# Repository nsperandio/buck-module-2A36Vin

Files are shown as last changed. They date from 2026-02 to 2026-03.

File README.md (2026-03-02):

# Buck DC/DC Module [Imax=2A, Vinmax=36V, Vo=5V]
Simple DC/DC converter in an simple and usable form-factor for educational or hobbyist purposes - but still with decent EMI performance and efficiency.

>⚠️ **Work in Progress**  
This design is currently under development and has not yet been fully validated.

## Current Project Status

- [x] Basic schematic
- [x] PCB layout
- [ ] BOM 
- [ ] First prototype assembly
- [ ] Electrical validation
- [ ] Thermal characterization

## Overview
The design is based on the [LV14240](https://www.ti.com/product/LV14240) buck controller with integrated switch by Texas Instruments.

Layout is based on the "Application and Implementation" section of the datasheet.

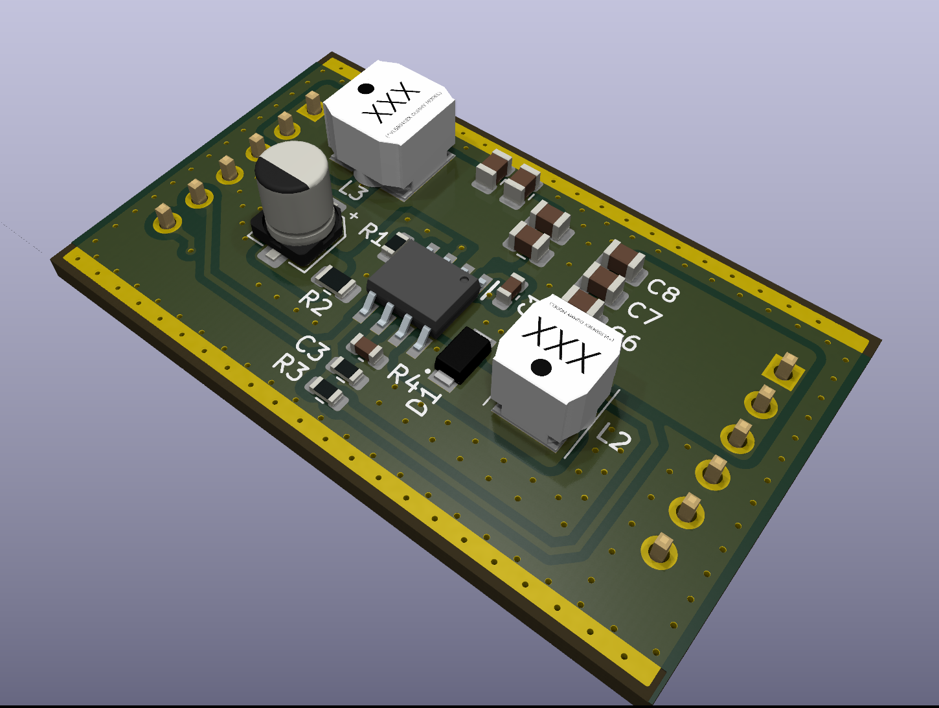
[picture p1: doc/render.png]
Buck PCB Render


## Specifications
|Spec|Value|
|-|-|
|Topology | buck (non-synchronous!)|
|Input Voltage| 4 - 36 V|
|Output Voltage| 5 V |
|Maximum Output Current| 2 A |
| Switching frequency| 500 kHz|

## EMI Considerations

An LCR input filter is added to attenuate conducted emissions at the switching frequency. The filter's damping factor can be obtained thanks to the ESR of the bulk capacitor and the DCR of the inductor. If the parasitics are not high enough an additional resistor can be used. 
The following plots refer to the components in the table. Modulus of the buck input impedance in green, modulus of the filter impedance in red:



|Spec|Value|
|-|-|
|Input Inductance| 47 uH|
|Inductors DCR| 230 mOhm|
|Bulk Capacitor| 20 uF |
|Capacitor ESR| 40 mOhm|
|Resonant peak frequency| 4.5 kHz|

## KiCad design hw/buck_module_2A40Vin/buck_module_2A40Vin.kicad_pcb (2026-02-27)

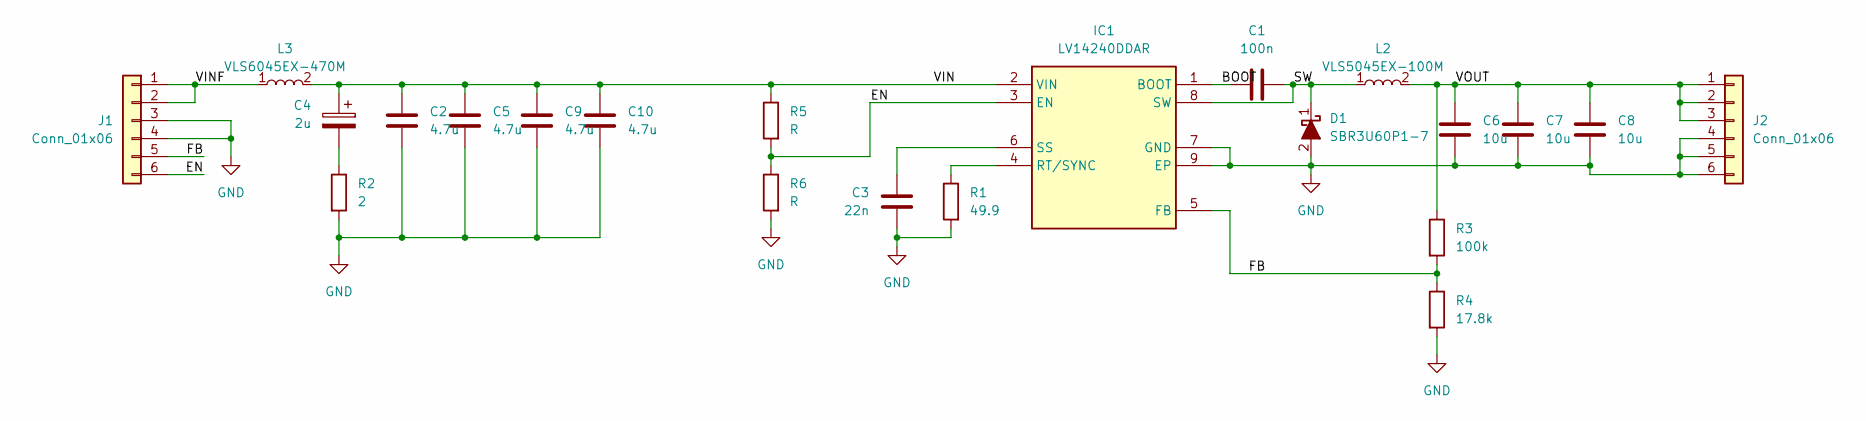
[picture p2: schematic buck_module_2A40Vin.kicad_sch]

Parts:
C1: 100n; C_0603_1608Metric; Voltage 16
C2, C5, C9, C10: 4.7u; C_0805_2012Metric; Voltage 100
C3: 22n; C_0603_1608Metric
C4: 2u; CP_Elec_4x5.4
C6: 10u; C_0805_2012Metric; Voltage 16
C7, C8: 10u; C_0805_2012Metric; Voltage 16V
D1: SBR3U60P1-7; SBR3U60P17; Mouser Part Number 621-SBR3U60P1-7
IC1: LV14240DDAR; SOIC127P600X170-9N; Manufacturer_Part_Number LV14240DDAR
J1, J2: Conn_01x06; PinHeader_1x06_P2.54mm_Vertical
L2: VLS5045EX-100M; VLS5045EX330M; Mouser Part Number 810-VLS5045EX-100M
L3: VLS6045EX-470M; VLS6045; Mouser Part Number 810-VLS6045EX-470M
R1: 49.9; R_0603_1608Metric
R2: 2; R_0805_2012Metric
R3: 100k; R_0603_1608Metric
R4: 17.8k; R_0603_1608Metric
R5, R6: R; R_0603_1608Metric

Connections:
/BOOT: C1.1, IC1.1 (BOOT)
/EN: IC1.3 (EN), J1.6, R5.2, R6.1
/FB: IC1.5 (FB), J1.5, R3.2, R4.1
/SW: C1.2, D1.1 (K), IC1.8 (SW), L2.1
/VIN: C2.2, C4.1, C5.2, C9.2, C10.2, IC1.2 (VIN), L3.2, R5.1
/VINF: J1.1, J1.2, L3.1
/VOUT: C6.2, C7.2, C8.2, J2.1, J2.2, J2.3, L2.2, R3.1
GND: C2.1, C3.1, C5.1, C6.1, C7.1, C8.1, C9.1, C10.1, D1.2 (A), IC1.7 (GND), IC1.9 (EP), J1.3, J1.4, J2.4, J2.5, J2.6, R1.2, R2.2, R4.2, R6.2
unnamed: C4.2, R2.1
unnamed: IC1.4 (RT/SYNC), R1.1
unnamed: C3.2, IC1.6 (SS)

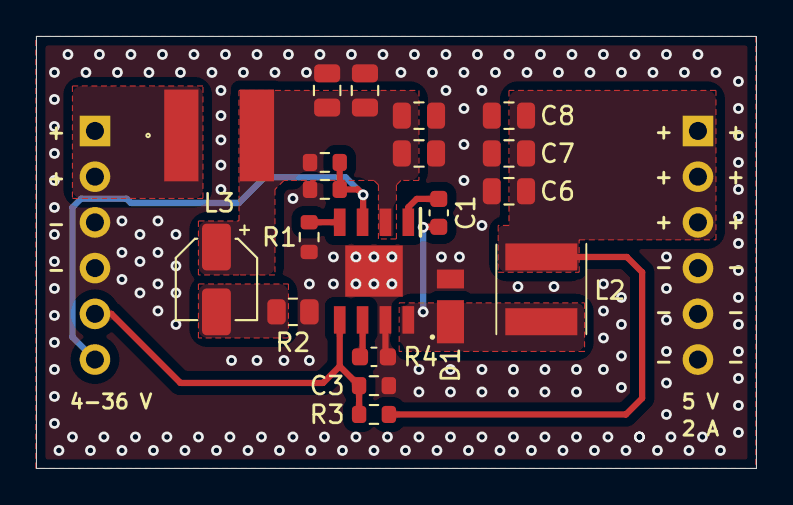
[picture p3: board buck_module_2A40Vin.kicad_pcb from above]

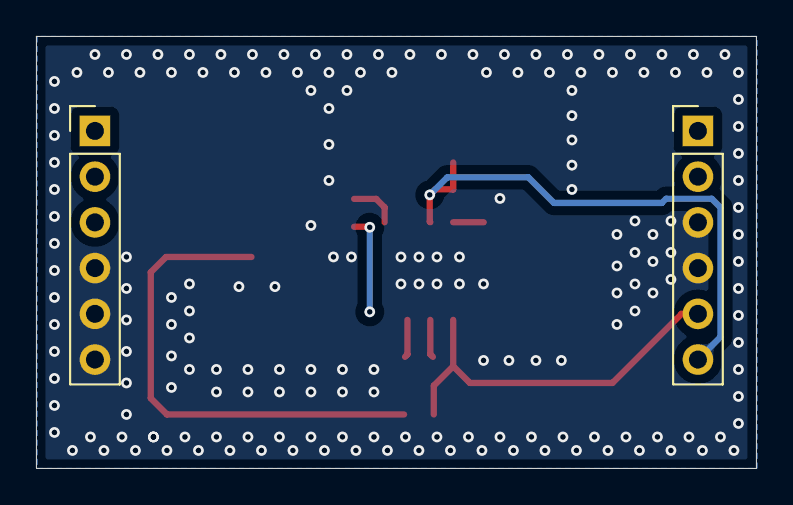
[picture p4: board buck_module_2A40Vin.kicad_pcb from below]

Board: 2 copper layers, 40.0 x 24.0 mm, 22 parts (2 on the bottom side), 11 nets.

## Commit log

2026-02-27 Added PCB (schematics, layout, rev0.1)
    [buck_module_2A40Vin.kicad_pcb, buck_module_2A40Vin.kicad_sch]
2026-02-27 Added silkscreen markings on the PCB
    [buck_module_2A40Vin.kicad_pcb]
2026-02-28 Update README.md
    added input filter transfer function image
2026-02-28 Added Simplis simulation for input filter design
    [buck_module_2A40Vin.kicad_sch]
2026-03-02 added schematics in readme
